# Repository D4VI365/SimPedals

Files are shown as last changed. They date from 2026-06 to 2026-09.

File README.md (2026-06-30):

# SimPedals
Simple DIY simulator pedals to use on my pc.

it's pretty simple how they work, The brake pedal uses a load cell as an input to get a better feeling and the accelerator and clutch use ss49e hall sensors to get the input value. The pedal's body are made out of 304 stainless steel and to get the feedback  they use dyecast springs and skateboard bushings for the brake. Everything will be contrtolled via custom software on an arduino pro micro.

Accelerator pedal:
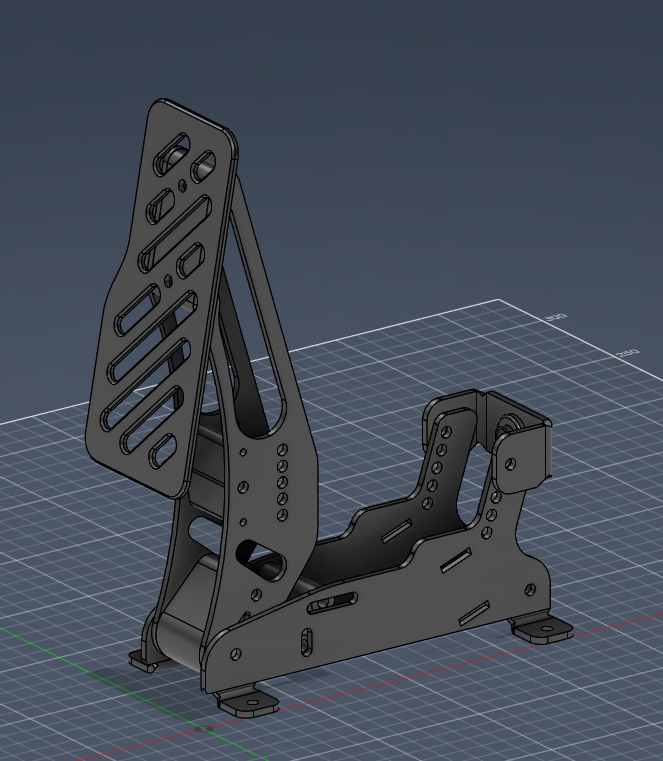
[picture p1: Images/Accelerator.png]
Accelerator


Brake pedal:
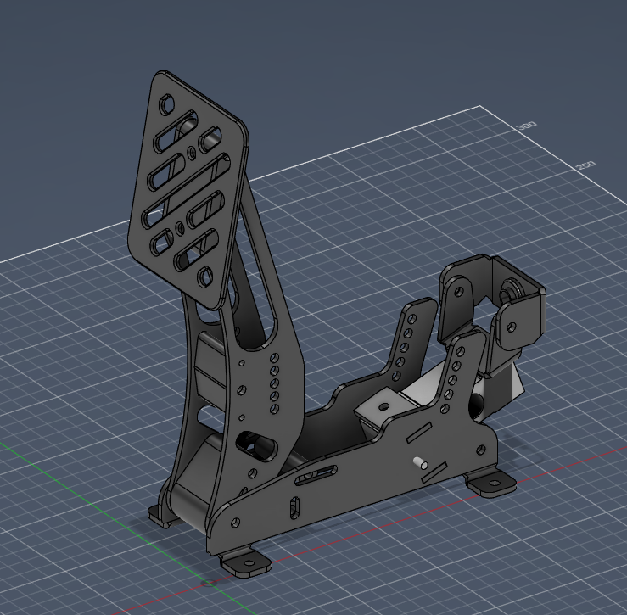
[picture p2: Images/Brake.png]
Brake


Clutch pedal:
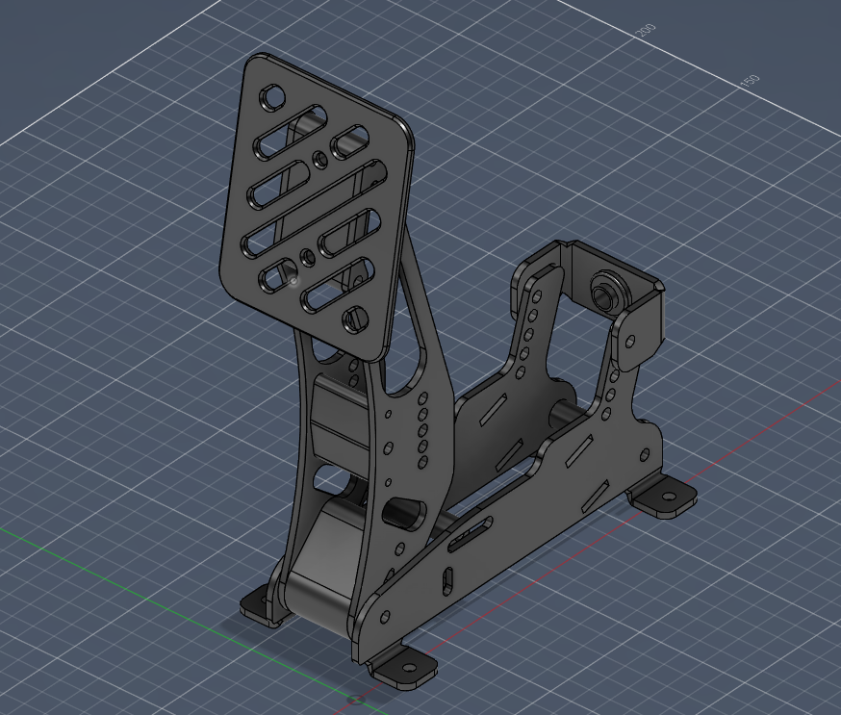
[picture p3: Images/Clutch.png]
Clutch


Electrical scheme:
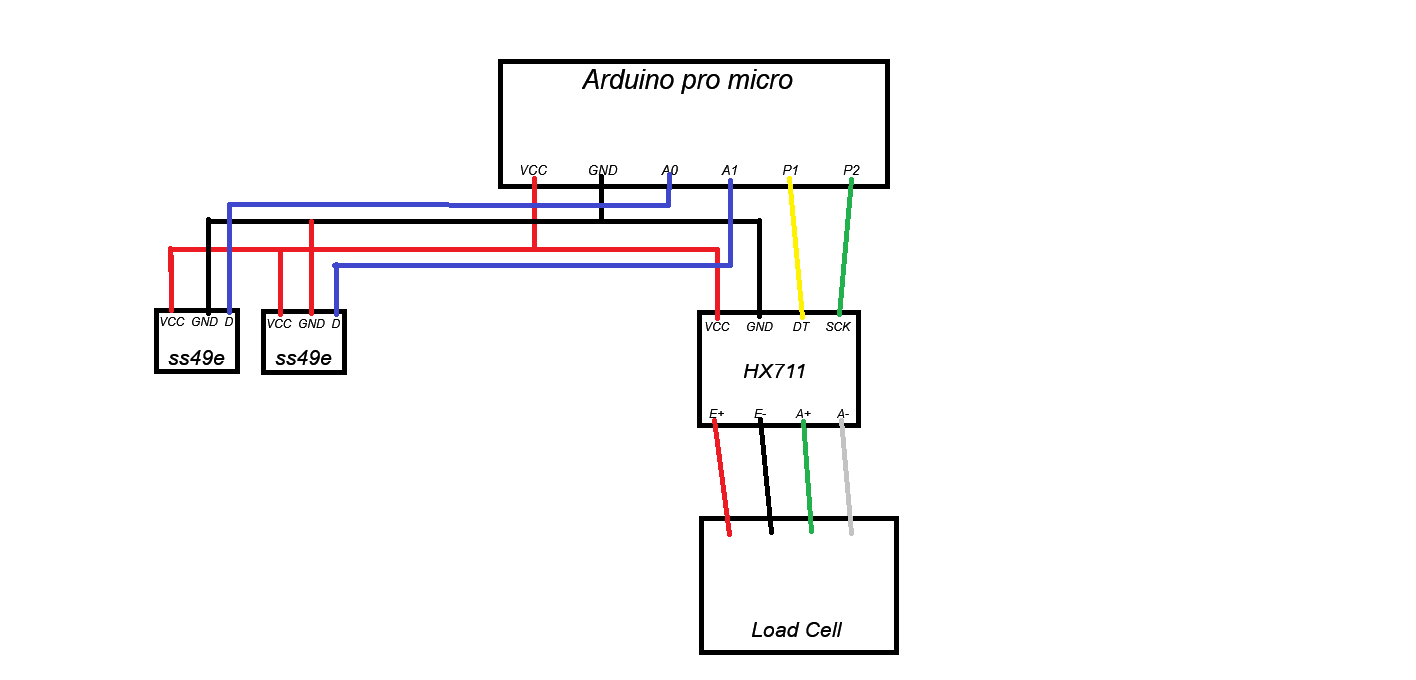
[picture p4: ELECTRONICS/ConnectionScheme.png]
ConnectionScheme


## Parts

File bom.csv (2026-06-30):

Name | Purpose | Quantity | Total Cost (USD) | Link | Distributor
Metal plates | The structure of the pedals | 1 | 114.83 | https://trade.jlcpcb.com/ | JLCPCB (CNC/sheet metal section)
Endrod bearings | feedback assebly joint | 3 | 9.45 | https://it.aliexpress.com/item/1005009480601086.html | Aliexpress
688RS bearings | Pedal joints | 6 | 7.95 | https://it.aliexpress.com/item/1005003726227462.html | Aliexpress
usb -> usb-c cable | Connecting pedals to pc | 1 | 4.19 | https://www.aliexpress.com/item/1005006729452564.html?spm=a2g0o.cart.0.0.810a18fcCWE3qo&mp=1 | Aliexpress
100Kg load cell | brake pedal sensing | 1 | 18.34 | https://www.aliexpress.com/item/1005008298196979.html?mp=1 | Aliexpress
HX711 high precision | load cell controlling | 1 | 1.56 | https://www.aliexpress.com/item/1005007284542958.html?spm=a2g0o.cart.0.0.18a118fcP8vIPM&mp=1 | Aliexpress
M5 nuts and bolts | mounting the panels | 1 | 16.00 | https://www.aliexpress.com/item/1005005478212295.html?spm=a2g0o.cart.0.0.78bb18fc2mM98V&mp=1 | Aliexpress
m8 threaded rods | Brake feedback assemblies | 3 | 11.14 | https://www.aliexpress.com/item/1005008512534705.html?spm=a2g0o.cart.0.0.18a118fcP8vIPM&mp=1 | Aliexpress
M8 washers | brake stiffness | 6 | 4.17 | https://www.aliexpress.com/item/1005009412753888.html?spm=a2g0o.cart.0.0.18a118fcP8vIPM&mp=1 | Aliexpress
skateboard bushings 90a & 95a | brake stiffness | 4 | 6.63 | https://www.aliexpress.com/item/1005006618326898.html?spm=a2g0o.cart.0.0.18a118fcP8vIPM&mp=1 | Aliexpress
m8 self locking nuts | pedals feedback assembly | 6 | 2.49 | https://www.aliexpress.com/item/1005009539464446.html?spm=a2g0o.cart.0.0.18a118fcP8vIPM&mp=1 | Aliexpress
Diecast springs | rigidity feedback for the pedals | 3 | 10.43 | https://www.aliexpress.com/item/1005006430460950.html?spm=a2g0o.cart.0.0.18a118fcP8vIPM&mp=1 | Aliexpress
Ardiono Pro Micro | Controlling the input of the pedals | 1 | 5.03 | https://www.aliexpress.com/item/32846843498.html?spm=a2g0o.cart.0.0.18a118fcP8vIPM&mp=1 | Aliexpress

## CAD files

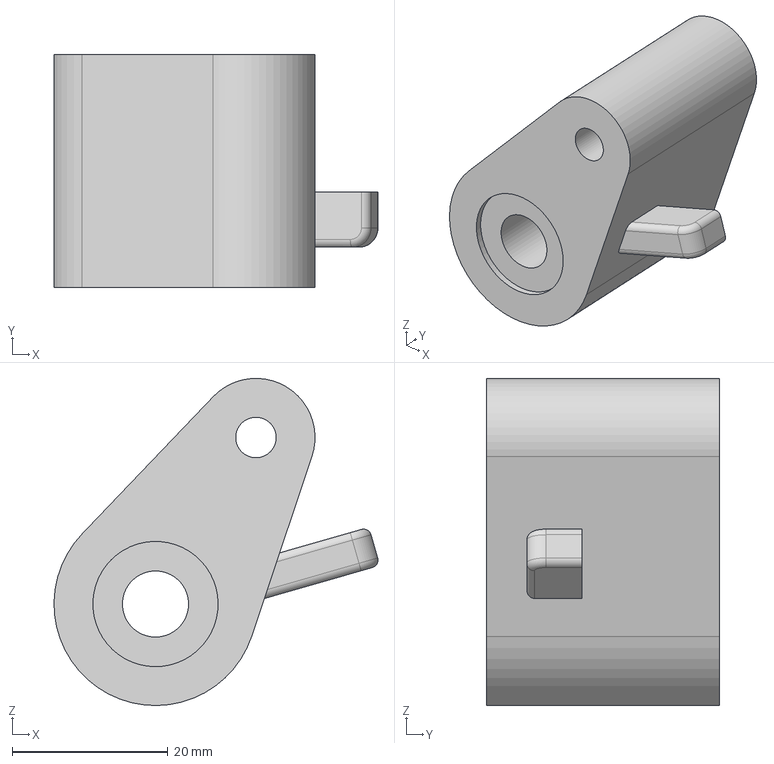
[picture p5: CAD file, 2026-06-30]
CAD/3D Printed/BottomPedalSpacer.step
41.7 x 30.0 x 42.0 mm

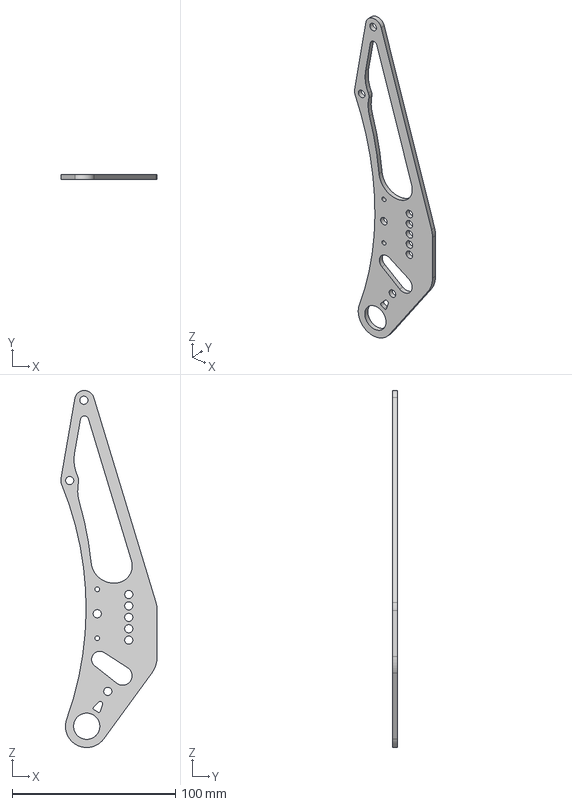
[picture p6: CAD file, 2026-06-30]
CAD/Metal Plate/PedalPlate.step
59.2 x 3.00 x 219.0 mm

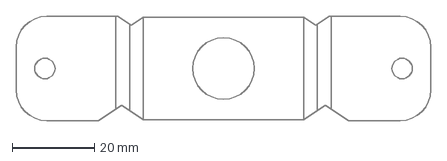
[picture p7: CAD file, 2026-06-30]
CAD/3D Printed/SpringSupport v2.dxf
101.0 x 25.4 mm

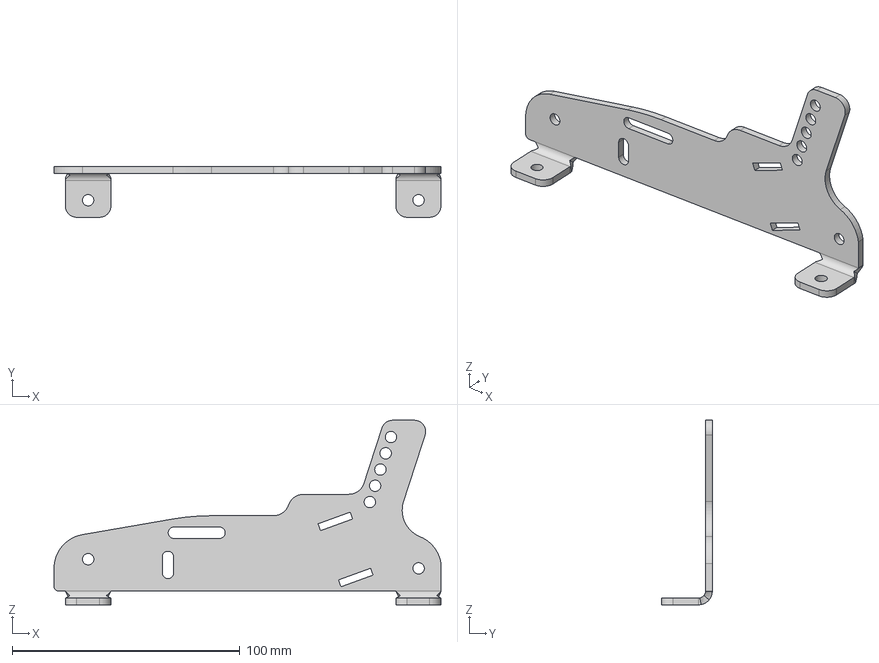
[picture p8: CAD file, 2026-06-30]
CAD/Metal Plate/SidePlate.step
169.8 x 22.2 x 81.0 mm

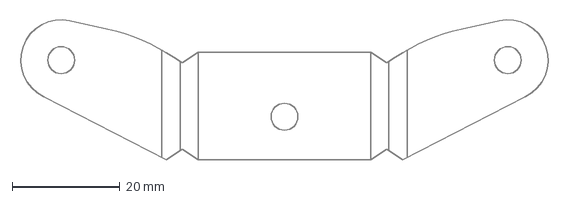
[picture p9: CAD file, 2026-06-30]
CAD/3D Printed/LoadCellTransmission v11.dxf
99.6 x 26.7 mm

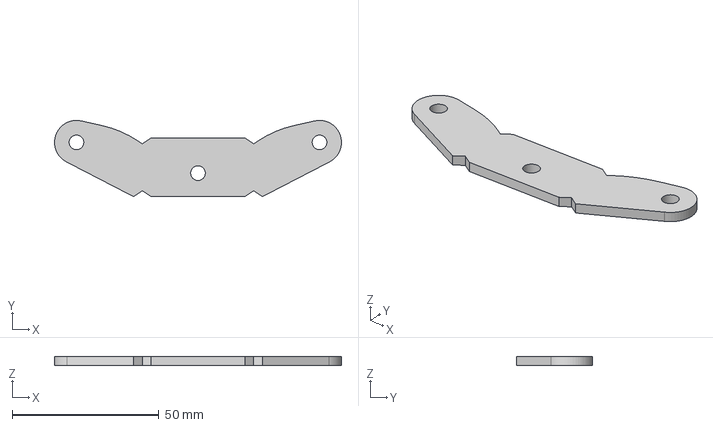
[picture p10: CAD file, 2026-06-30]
CAD/Metal Plate/LoadCellTransmissionPlane.step
97.9 x 26.0 x 3.00 mm

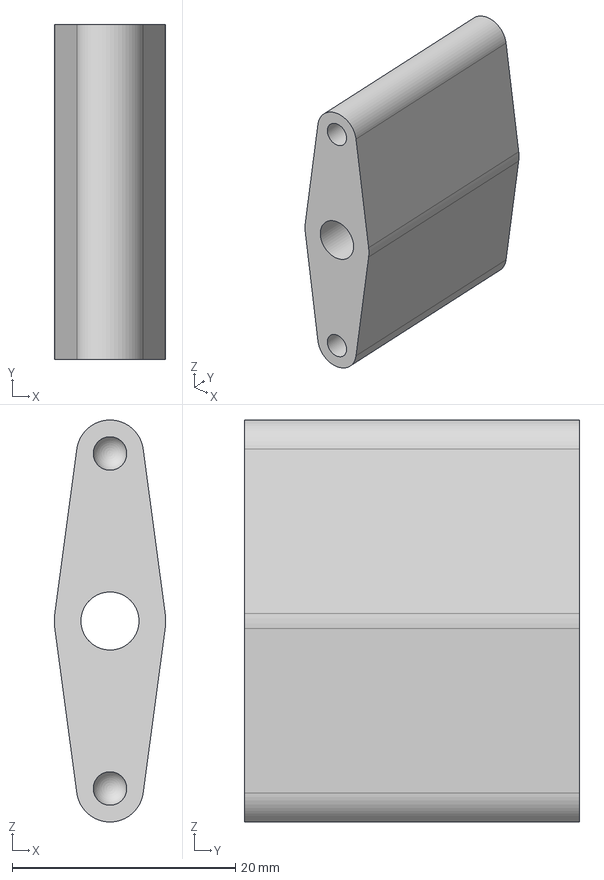
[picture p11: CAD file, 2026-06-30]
CAD/3D Printed/MiddlePedalSpacer.step
9.97 x 30.0 x 36.0 mm

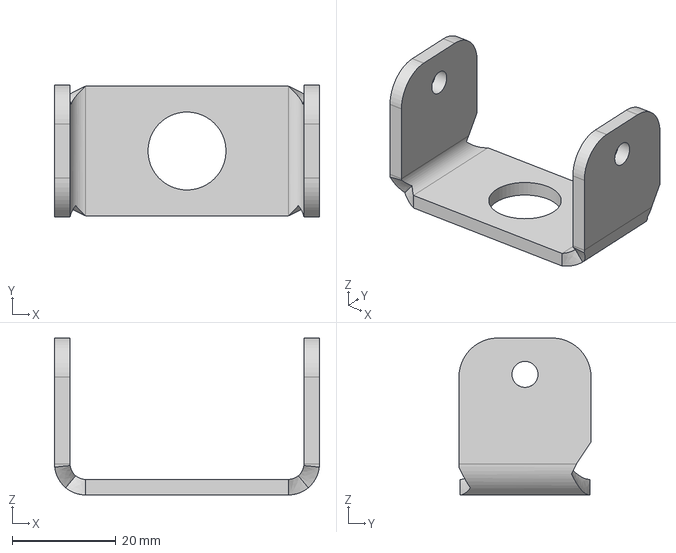
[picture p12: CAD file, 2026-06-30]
CAD/Metal Plate/SpringSupport.step
51.0 x 25.4 x 30.2 mm

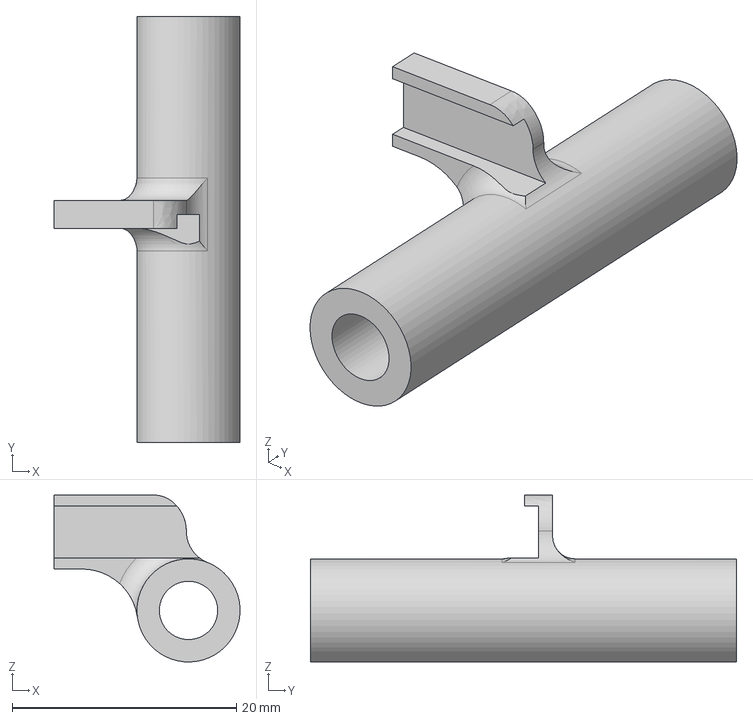
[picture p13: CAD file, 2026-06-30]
CAD/3D Printed/HallHolder.step
16.6 x 38.0 x 14.9 mm

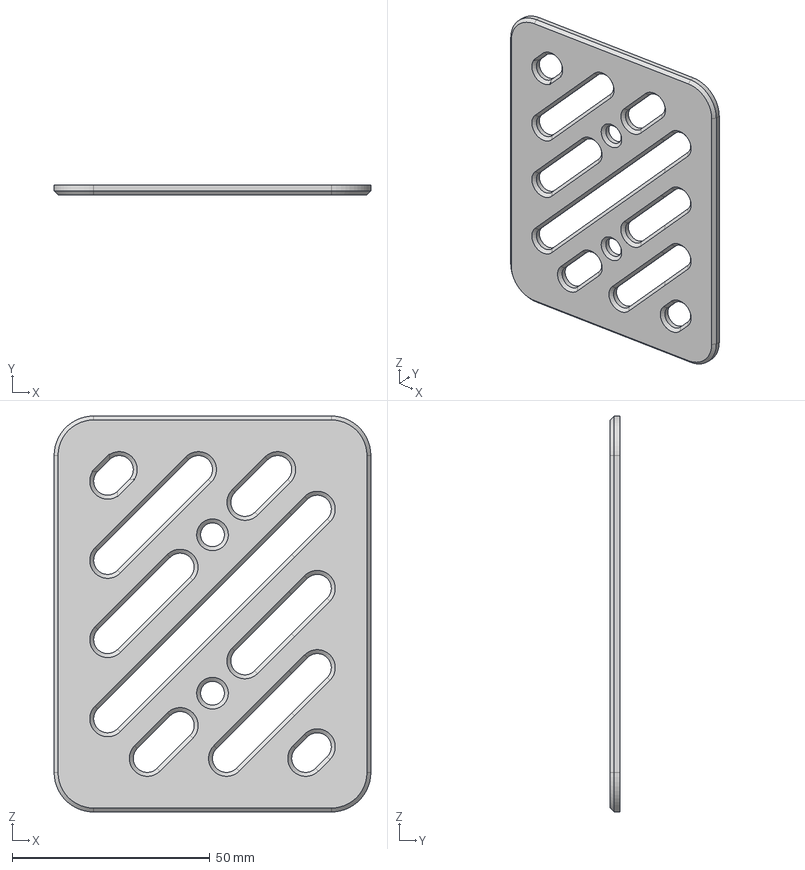
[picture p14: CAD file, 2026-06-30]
CAD/Metal Plate/BrakeClutchPlate.step
80.0 x 2.50 x 100.0 mm

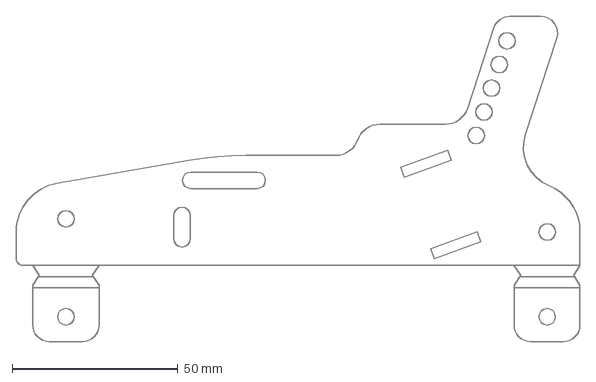
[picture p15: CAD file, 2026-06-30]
CAD/3D Printed/SidePlate v5.dxf
169.8 x 98.0 mm

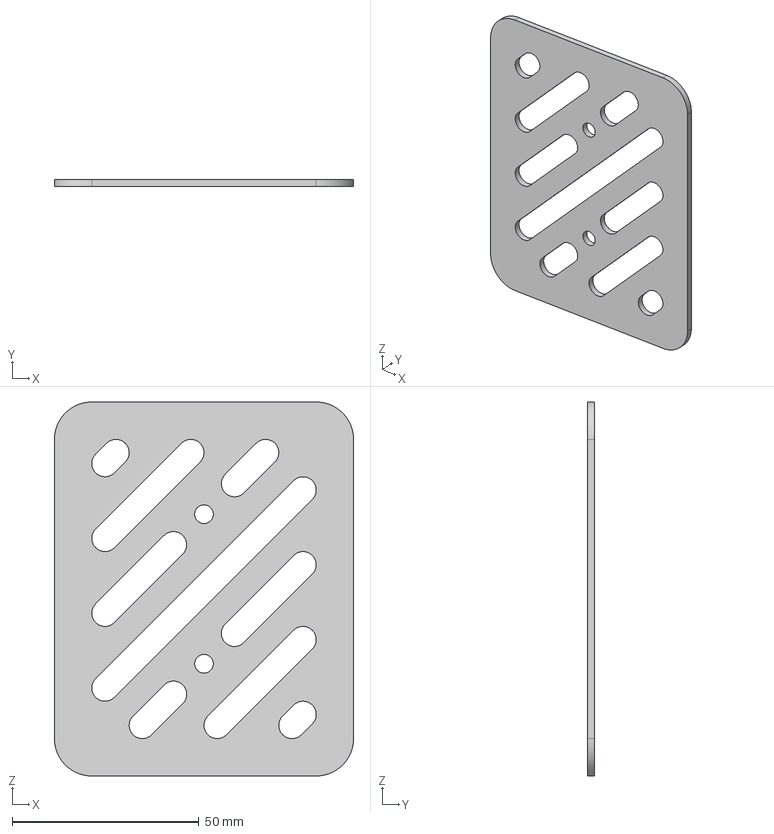
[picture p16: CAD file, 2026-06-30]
CAD/Metal Plate/BrakeClutch.step
80.0 x 2.00 x 100.0 mm

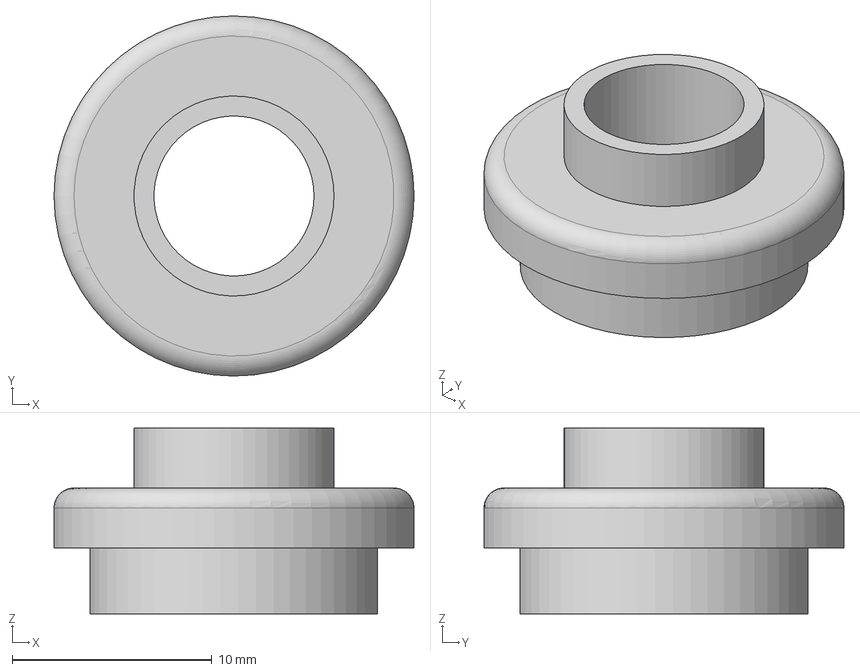
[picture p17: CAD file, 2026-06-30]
CAD/3D Printed/SpringHolder.step
18.0 x 18.0 x 9.30 mm

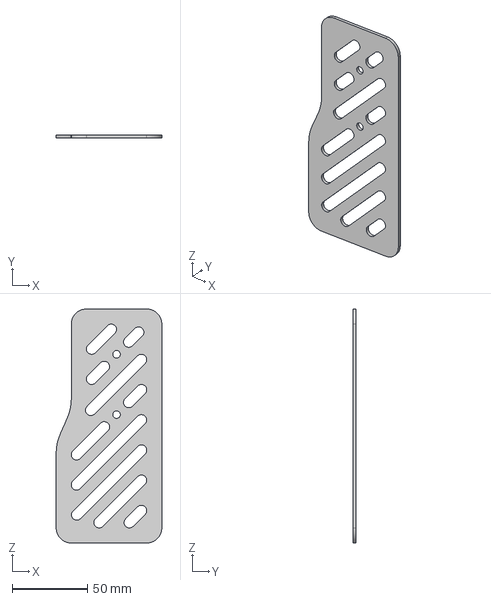
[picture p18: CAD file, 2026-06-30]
CAD/Metal Plate/Accelerator.step
70.0 x 2.00 x 155.0 mm

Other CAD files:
CAD/3D Printed/NormalSpacer.step
CAD/Metal Plate/SpringSupportFlat.step
CAD/3D Printed/PedalPlateHolder.step
CAD/Metal Plate/LoadCellTransmission.step
CAD/3D Printed/BottomPedalSpacer.stl
CAD/3D Printed/HallHolder.stl
CAD/3D Printed/MiddlePedalSpacer.stl
CAD/3D Printed/NormalSpacer.stl
CAD/3D Printed/PedalPlateHolder.stl
CAD/3D Printed/SpringHolder.stl
CAD/Metal Plate/Accelerator.stl
CAD/Metal Plate/AcceleratorPlate.step
CAD/Metal Plate/AcceleratorPlate.stl
CAD/Metal Plate/BrakeClutch.stl
CAD/Metal Plate/BrakeClutchPlate.stl
CAD/Metal Plate/LaodCellHolder.step
CAD/Metal Plate/LaodCellHolder.stl
CAD/Metal Plate/LoadCellTransmission.stl
CAD/Metal Plate/PedalPlate.stl
CAD/Metal Plate/SidePlate.stl
CAD/Metal Plate/SidePlateFlat.f3d
CAD/Metal Plate/SidePlateFlat.step
CAD/Metal Plate/SidePlateMirrored.step
CAD/Metal Plate/SidePlateMirrored.stl
CAD/Metal Plate/SpringSupport.stl

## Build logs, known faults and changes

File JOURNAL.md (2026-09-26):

<!--
  This journal is auto generated by Stasis.
-->

# 6/21/2026 9 PM - Almost got a heart attack

_Time spent: 0.08333333333333333h_

I almost got a heart attack when I went to see how muche the metal parts would cost because that's a lot. As of now I'm adding this cost to the BOM but before submitting it for review I will try and lower the price in some way.





# 6/14/2026 1 PM - Finished (almost)

_Time spent: 2.5h_

Today I eally worked hard to bring this project to the end and I was actually able to. Sadly I had to scrap the idea of building the base for the pedals with aluminum extrusion because they cost way too much so I went back to the original idea of boign the baseplate with some leftover wood I already have at home. I'm not able to add this to the design since the wood is at my grandparent's house and I don't have the dimensions. So what did I do? I went on and drew the electrical connections scheme and wrote the firmware, I will patch it afterwards if it is not working. I now have to axport all the 3d models from fusion and upload them to jlccnc to get the price for the metal parts. I will add another journal when the repo is complete.

ConnectionScheme






# 6/13/2026 10 PM - Finished modeling the 3D printed parts

_Time spent: 3h_

I designed all the parts that will be 3d printed, the ones which took more time were the hall sensor holder and bottom pedal spacer and magnet holder because I had to make some measurements right to have a clean signal in the code later on. The things I'm missing now are only the base and the code. (I will not add the springs assembly in the 3D models since they are simply stacked up on the threaded rod.

Hall sensor and magnet section:


Hall sensor holder:


Bottom pedal spacer and magnet support:


Spring holder:


Accelerator pedal:


Brake pedal:


Clutch pedal:










# 6/7/2026 9 PM - Continued working on CAD

_Time spent: 4h_

Today I kept working on the CAD modes for the metal parts, I finished the pedal plates. Did the main body plates and all the parts for the brake and load cell adaptation. Now I need to design all the 3d printed parts like spacers and slots for magnets and sensors. I'm also considering adding a 20x20 extrusion base. My initial idea was to use a wood panel as base but it might be too fragile and fray with use.
















# 6/6/2026 9 PM - Started working on cad

_Time spent: 3.5h_

Today after some more research and after I made the BOM I started wotking on the cad models of the various plates, specifically the pedal plates and started designing the side supports for the pedals. It took a lot of time beacuse I never used the sheet metal environment.










# 5/20/2026 8 PM - Initial research

_Time spent: 1.25h_

Ok, so to go with the custom DD wheel I'm also designing these pedals. The design itself probably won't be that complicated but now I'll only explain the working principle.
To avoid problems caused by wear and dirt the accelerator and clutch pedal will use ss49e hall effect sensors and magnets to get the position. To make it more realistic the brake pedal will use a load cell (still to decide the value) to measure the force applied to the pedal and not the position itself. To make resistance every pedal will have a compression sping with some sort of adjustable stiffness. Everything will be powered by an arduino nano as it doesn't need anything powerful to get the values and transmit them to the computer. for the design and mechanical working principle I will take inspiration from [this video](https://www.youtube.com/watch?v=44LWekyILmk) as it looks really well made and adjustable. I WILL NOT TAKE THE FILES AND REUPLOAD THEM, I WILL ONLY TAKE INSPIRATION AND MAKE MY OWN.





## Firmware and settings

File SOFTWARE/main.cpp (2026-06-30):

#include <Joystick.h>
#include <HX711.h>

// ==========================================
// CONFIGURAZIONE PIN
// ==========================================
const int PIN_ACCEL  = A0;
const int PIN_CLUTCH = A1;
const int PIN_DT     = 2;
const int PIN_SCK    = 3;

// ==========================================
// INIZIALIZZAZIONE OGGETTI
// ==========================================
// Creiamo un Joystick con 3 assi (X, Y, Z) e nessun pulsante
Joystick_ Joystick(JOYSTICK_DEFAULT_REPORT_ID, JOYSTICK_TYPE_MULTI_AXIS, 
                   0, 0,                   // Numero di pulsanti e Hat Switch
                   true, true, true,       // Attiva asse X, Y, Z
                   false, false, false,    // Disattiva Rx, Ry, Rz
                   false, false,           // Disattiva Timone e Throttle
                   false, false, false);   // Disattiva Acceleratore, Freno, Sterzo dedicati (usiamo X,Y,Z per massima compatibilità)

HX711 scale;

// ==========================================
// PARAMETRI DI CALIBRAZIONE (DA MODIFICARE)
// ==========================================
// I sensori SS49E a riposo (nessun campo magnetico) leggono circa 512.
// Quando avvicini il magnete, il valore sale (es. fino a 850) o scende (es. fino a 200) a seconda del polo (Nord/Sud).
// DOVRAI INSERIRE I TUOI VALORI REALI DOPO AVERLI LETTI SUL SERIAL MONITOR.
int accelMin = 512;  // Valore a pedale rilasciato
int accelMax = 850;  // Valore a pedale premuto al 100%

int clutchMin = 512; // Valore a pedale rilasciato
int clutchMax = 200; // Valore a pedale premuto al 100% (se usi l'altro polo magnetico, il numero scende!)

// Cella di carico (HX711)
float hx711_calibration_factor = 100.0; // Da calcolare durante la taratura
long brakeMaxRaw = 25000;               // Lettura grezza della cella a massima frenata desiderata

// ==========================================
// VARIABILI PER FILTRO SOFTWARE (EMA)
// ==========================================
// Aiuta a stabilizzare la lettura rimuovendo i micro-sfarfallii
float filteredAccel = 0;
float filteredClutch = 0;
float alpha = 0.2; // Forza del filtro (0.0 = massimo filtro/lento, 1.0 = nessun filtro/istantaneo)

void setup() {
  Serial.begin(115200);

  // Inizializza l'HX711
  scale.begin(PIN_DT, PIN_SCK);
  scale.set_scale(hx711_calibration_factor);
  scale.tare(); // Azzera la cella di carico all'avvio del Pro Micro

  // Configura i range della periferica USB (0-1023 per massima risoluzione a 10 bit)
  Joystick.setXAxisRange(0, 1023); // Acceleratore
  Joystick.setYAxisRange(0, 1023); // Frizione
  Joystick.setZAxisRange(0, 1023); // Freno
  
  Joystick.begin();
}

void loop() {
  // --------------------------------------------------
  // 1. LETTURA E FILTRAGGIO ACCELERATORE E FRIZIONE
  // --------------------------------------------------
  int rawAccel = analogRead(PIN_ACCEL);
  int rawClutch = analogRead(PIN_CLUTCH);

  // Applico il filtro passa-basso EMA
  filteredAccel = (alpha * rawAccel) + ((1.0 - alpha) * filteredAccel);
  filteredClutch = (alpha * rawClutch) + ((1.0 - alpha) * filteredClutch);

  // Mappatura e costrizione dei valori nel range USB (0-1023)
  // constrain() è vitale: impedisce che il valore vada sotto lo 0 se il pedale va leggermente oltre il limite meccanico
  int mappedAccel = map(filteredAccel, accelMin, accelMax, 0, 1023);
  mappedAccel = constrain(mappedAccel, 0, 1023);

  int mappedClutch = map(filteredClutch, clutchMin, clutchMax, 0, 1023);
  mappedClutch = constrain(mappedClutch, 0, 1023);

  // --------------------------------------------------
  // 2. LETTURA CELLA DI CARICO (FRENO)
  // --------------------------------------------------
  int mappedBrake = 0;
  
  // scale.is_ready() evita che l'Arduino si blocchi aspettando l'HX711
  if (scale.is_ready()) {
    long rawBrake = scale.get_units(1); // Legge 1 campione
    
    // Se la cella va in negativo (perché l'hai montata al contrario), usa abs(rawBrake)
    mappedBrake = map(rawBrake, 0, brakeMaxRaw, 0, 1023);
    mappedBrake = constrain(mappedBrake, 0, 1023);
  }

  // --------------------------------------------------
  // 3. INVIO DATI AL PC TRAMITE USB
  // --------------------------------------------------
  Joystick.setXAxis(mappedAccel);
  Joystick.setYAxis(mappedClutch);
  Joystick.setZAxis(mappedBrake);

  // (OPZIONALE) Stampa per la calibrazione - Decommenta per leggere i valori grezzi
  /*
  Serial.print("Raw Accel: "); Serial.print(rawAccel);
  Serial.print(" | Raw Clutch: "); Serial.print(rawClutch);
  Serial.print(" | Raw Brake: "); Serial.println(scale.get_units(1));
  */

  delay(10); // Piccolo delay per stabilità USB (10ms = 100Hz di aggiornamento, ottimo per i pedali)
}
